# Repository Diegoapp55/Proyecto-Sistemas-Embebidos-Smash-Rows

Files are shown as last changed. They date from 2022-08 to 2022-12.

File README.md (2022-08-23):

# Proyecto-Sistemas-Embebidos
Repositorio para el proyecto de Sistemas Embebidos 2022-2: Smash Rows

En la wiki de este repositorio se encuentra la documentación al respecto del proyecto.

Integrantes: 
* Raúl Andrés Guzmán Mayorga
* Sergio Andrés Guevara Contreras
* Diego Alejandro Sánchez Mendoza
* Eduardo Toro Bernal

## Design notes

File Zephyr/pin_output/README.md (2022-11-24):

# GPIO output

Compilar firmware

```bash
make b
```

Subir firmware a esp32

```bash
make f
```

Conectarse por puerto serial al esp32

```bash
make t
```

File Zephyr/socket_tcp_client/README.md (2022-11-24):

# Cliente TCP

En este ejemplo el esp32 se conecta a la red wifi, solicita una ip a través del dhcp para finalmente conectarse
a un servicio 

## ¿Cómo reproducir este ejemplo?

1. Se requiere inicar el server, para lo cual deberá construir el servicio que se encuentra en `tcp_linux_server/`
para luego lanzarlo en la terminal, siga las instrucciones que encuentra en el README.md de ese directorio.

2. Deberá construir el firmware para el esp32, para lo cual modifique los siguientes datos en el prj.conf

## Comando útiles

* Consultar la ip asociada al esp32 desde el PC

```bash
sudo arp-scan --localnet
```

* Consultar la ip desde la uart-shell de zephyr os en el esp32

```bash
net iface
```

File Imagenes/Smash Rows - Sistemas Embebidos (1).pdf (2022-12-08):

# 2. ACTORES

# 1. CONTEXTO

## 3. PROPUESTA: SMASH ROWS

# SMASH ROWS

## Plataforma para agilizar las filas en las EPS

## 5. CONTROL ELECTRÓNICO

# 4. COMPONENTES

## 6. PROGRAMACIÓN

## 7. APLICACIONES

Sergio Andrés Guevara Contreras Raúl Andrés Guzmán Mayorga Diego Alejandro Sanchez Mendoza Eduardo Toro Bernal

Las EPS velan por brindar procesos ágiles y sencillos a los pacientes.

Se presenta una poca eficiencia en la entrega de medicamentos.

Principales causas de las demoras: Alta demanda, mayor cantidad de usuarios y falta de puntos de distribución y personal encargado.

Esto genera largas filas de espera, causando incomodidad en los usuarios.

Pacientes.
Distribuidoras de
medicamentos de las EPS.
Ministerio de salud.

Entidades de las EPS encargadas de distribuir medicamentos.
Droguerías.
Supermercados.

Smash Rows en un dispositivo que le permite al usuario conocer la disponibilidad de medicamentos en un punto de atención. Así, si este lo desea, puede realizar una dispensación automática a caja de sus medicinas asignadas, agilizando el proceso de búsqueda y entrega de estas.

El control se realiza desde la ESP32, la cual se encarga de manejar las señales de los motores y el WiFi. Adicionalmente, cuenta con un Arduino UNO que mediante un pin GPIO le manda información de lectura del módulo RFID a la ESP32.

La programación utilizada se realizó en Zephyr, un sistema operativo que permite escalabilidad y adaptabilidad a múltiples dispositivos, además de ser OpenSource. Se realizó el código de control de los motores, así como la integración de una bandera para el RFID y la conexión a un servicio mediante WiFi.

## 8. DOCUMENTACIÓN

ESP32 WRoom.
Reguladores: AMS117-5V y AMS117-3.3V. Módulo RFID: RC522.
Motores (2) paso a paso: 28-BYJ-48. (https://pdf1.alldatasheet.com/datasheet-pdf/view/1245086/ETC1/28BYJ48.html) Driver - ULN2003.
Diodo: 1N4007.
Módulo Optoacoplador.

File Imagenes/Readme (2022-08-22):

Todas las imágenes empleadas en la Wiki se almacenarán acá, estas son meramente ilustrativas.

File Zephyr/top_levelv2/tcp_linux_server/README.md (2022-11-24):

# Servidor TCP

Servicio que imprime en la terminal el mensaje que es recibido por un cliente, el servicio está activo
por el puerto 3000.

* Construir servidor:

```bash
gcc server.c -o server
```

* Lanzar servicio:

```bash
./server
```

* Detener servicio:

Para detener el servicio basta con oprimir el Ctrl junto a **c** `^c`

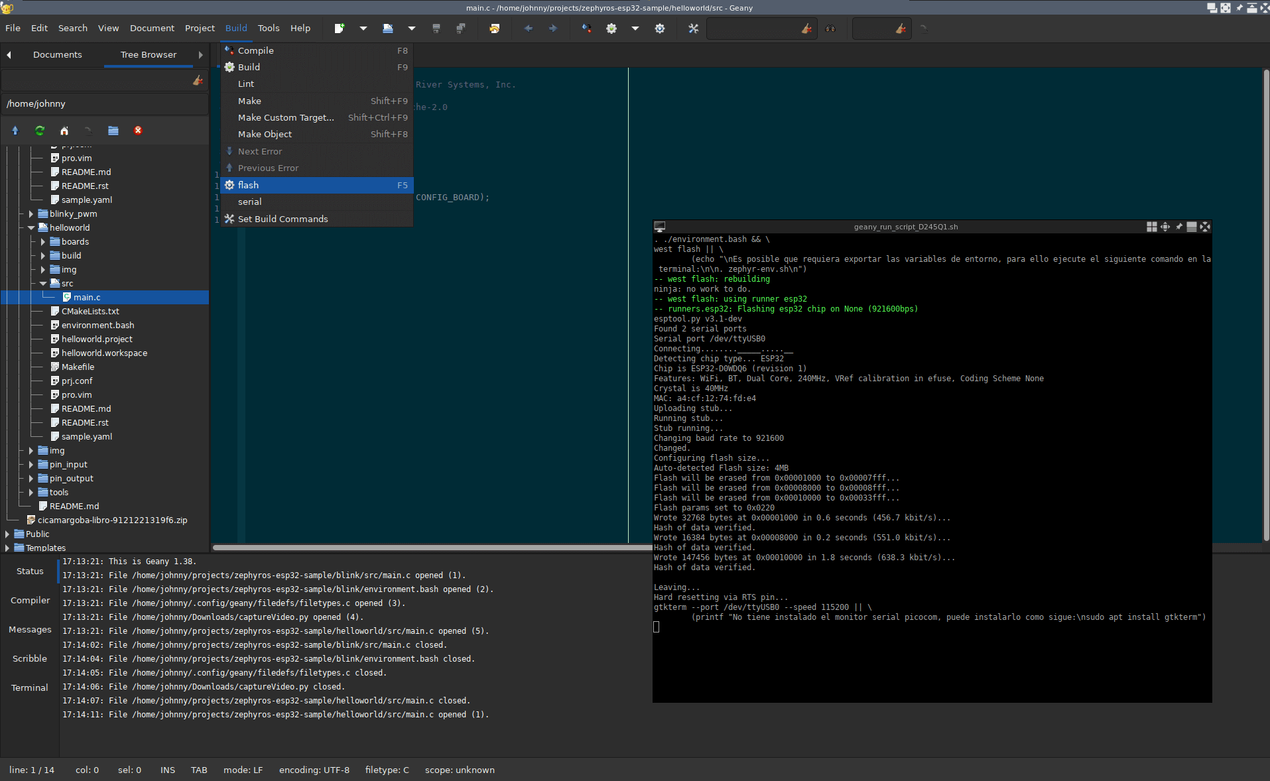
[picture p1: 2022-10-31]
Zephyr/img/geany-flash-esp32.png

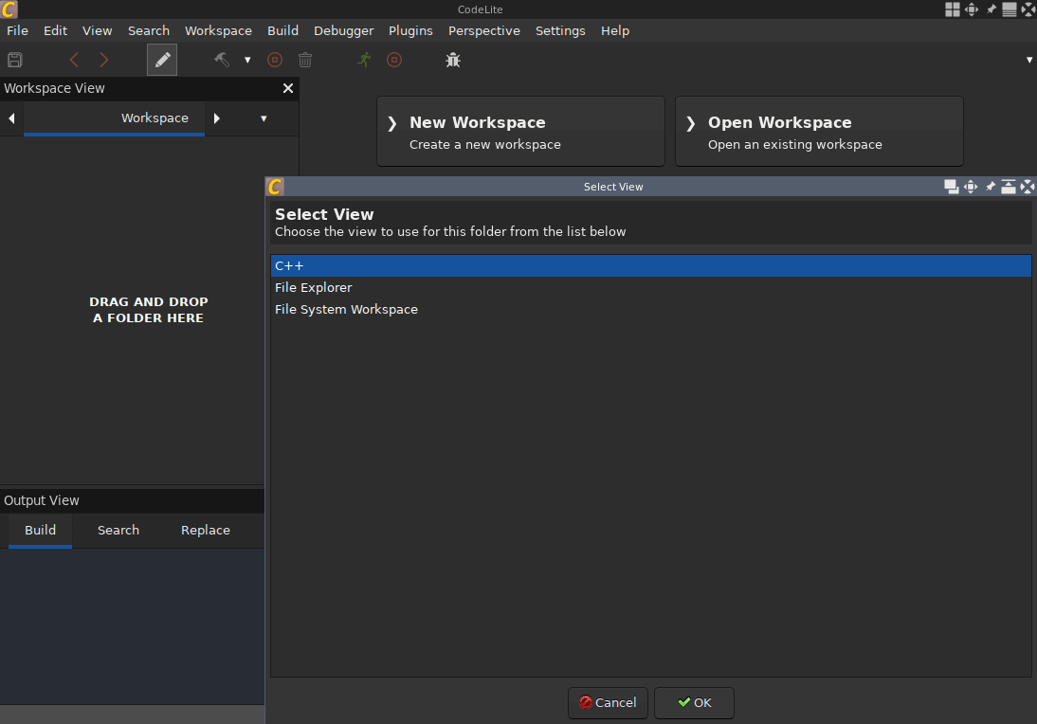
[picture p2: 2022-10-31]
Zephyr/img/codelite-select-view.png

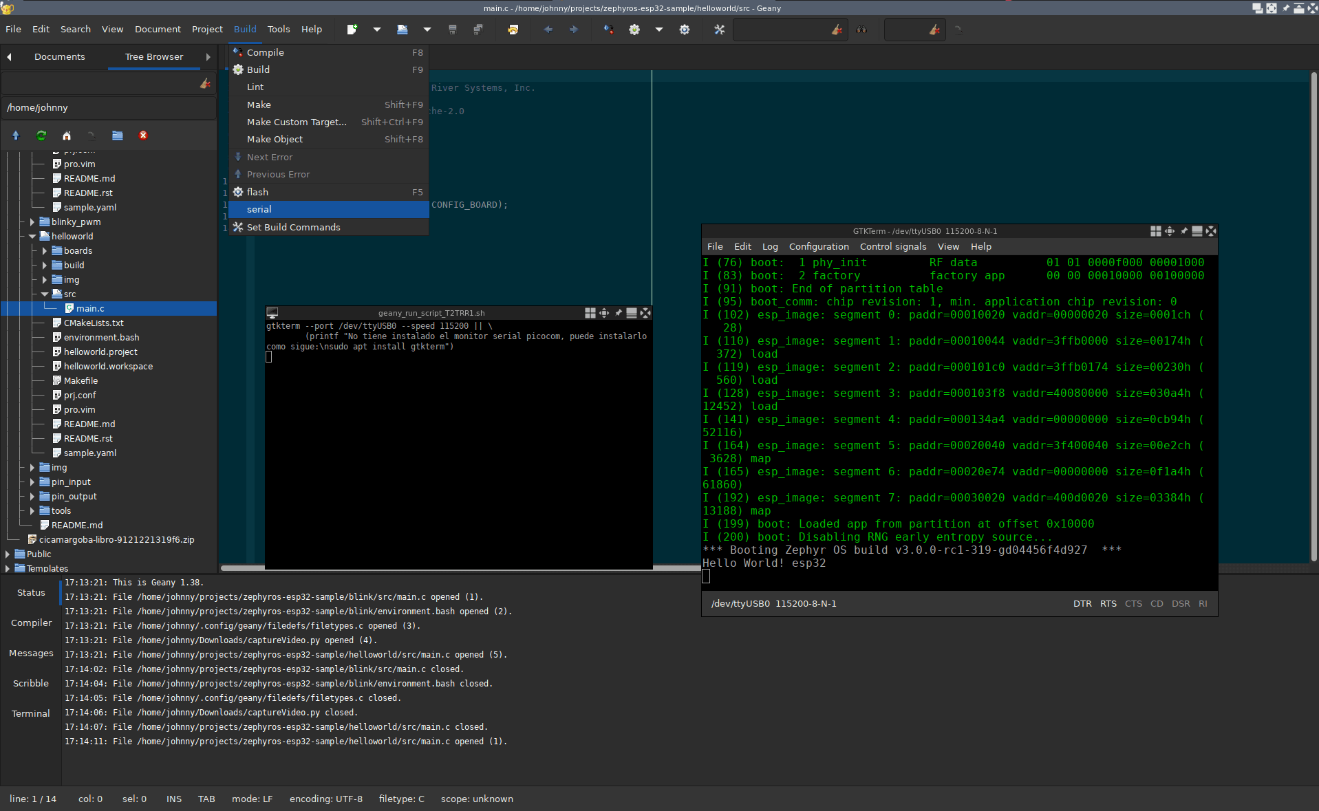
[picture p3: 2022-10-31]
Zephyr/img/geany-serial-esp32.png

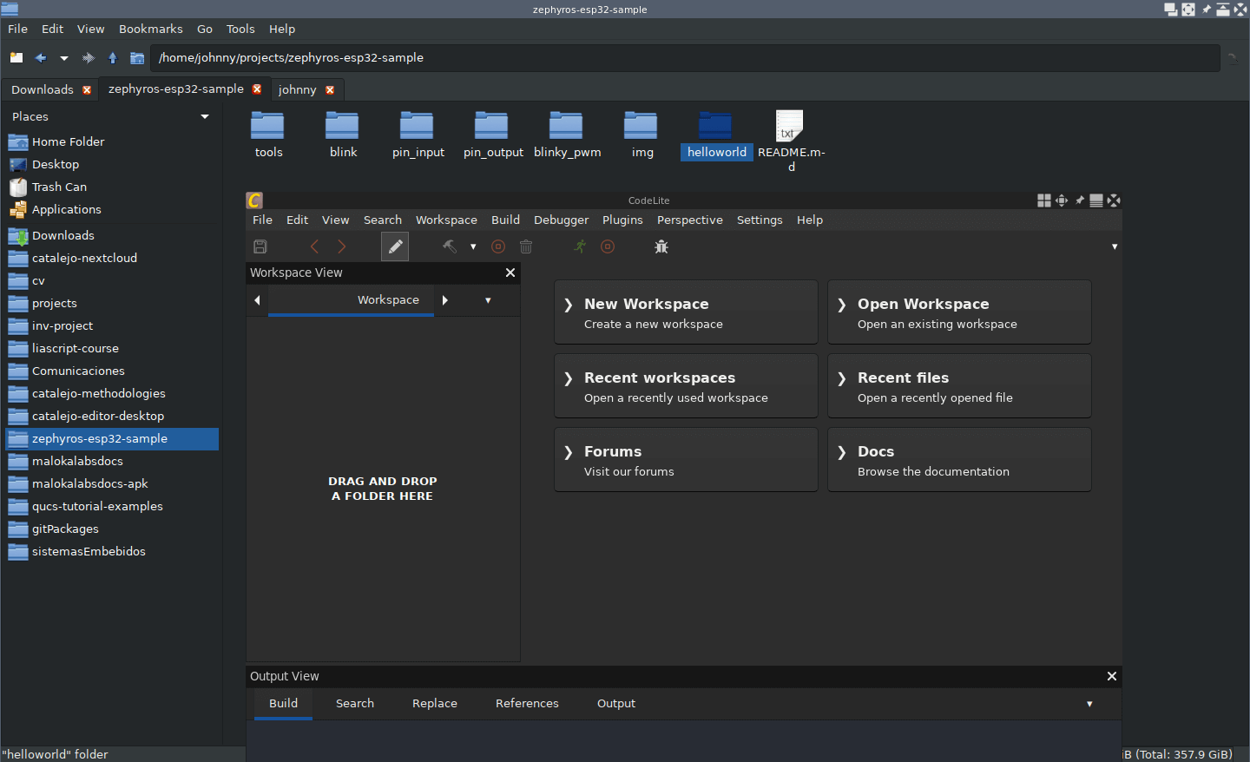
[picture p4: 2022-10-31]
Zephyr/img/codelite-drag-and-drop-prj.png

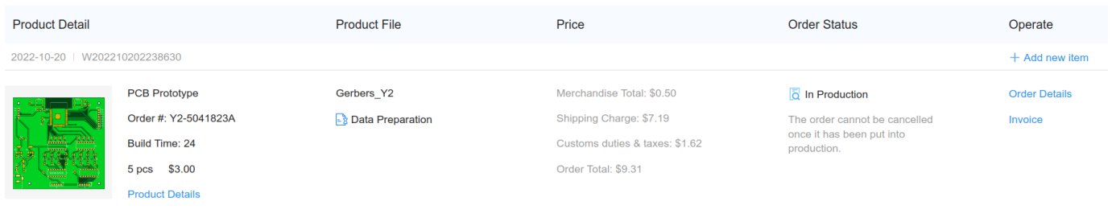
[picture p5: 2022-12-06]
Imagenes/orden_compra.png

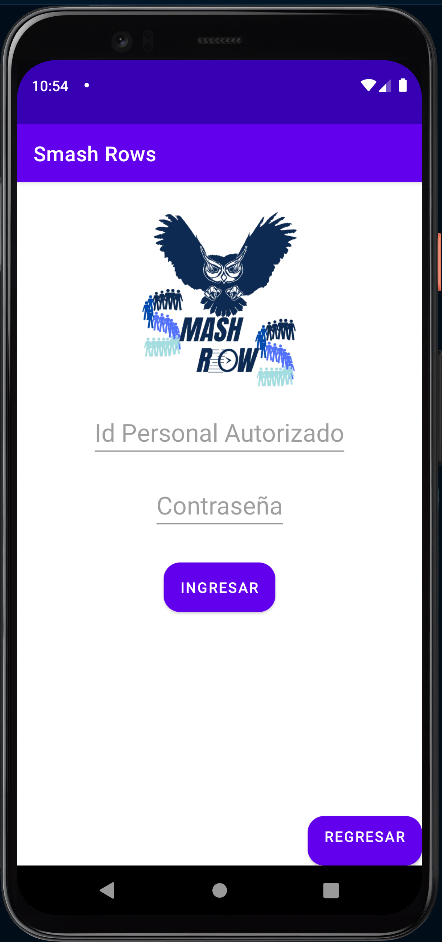
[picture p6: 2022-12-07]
Imagenes/App_Image/Login.png

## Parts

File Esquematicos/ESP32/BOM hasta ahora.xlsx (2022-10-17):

Column1 | Column2 | Column3
Source:
Date: | 16/10/2022 4:27:32 p. m.
Tool: | Eeschema (6.0.7)
Generator:
Component Count: | 72
Ref | Qnty | Value
BOOT1, | 1 | pulsador
C1, C2, C3, C4, C177, | 5 | 0.1uF
C11, C13, C15, C178, | 4 | 22uF
C12, C14, | 2 | 10uF
D1, | 1 | led
D2, | 1 | led
D3, | 1 | 1n4007
EN1, | 1 | pulsador
H1, H2, H3, H4, | 4 | NA
J1, | 1 | JST 1x5
J2, | 1 | JST 1x5
J3, | 1 | jack 12V
J4, | 1 | pin header hembra 1x5
Q1, Q2, Q3, Q4, Q5, Q6, Q7, Q8, | 8 | pnp s8550 o equiv
R1, R2, R3, R4, R9, R10, R11, R12, R13, R14, R15, R16, R21, R22, R23, R24, | 16 | 5.1kΩ
R5, R6, R7, R8, R17, R18, R19, R20, | 8 | 220Ω
R25, R27, | 2 | 10kΩ
R26, | 1 | 470Ω
R28, R29, | 2 | 56Ω
RRX1, | 1 | pend
RTX1, | 1 | pend
SW1, | 1 | dip switch x1
U1, U2, | 2 | ltv247 o equiv
U3, U4, | 2 | uln2003
U5, | 1 | ams1117-5V
U6, | 1 | ams1117-3V3
U7, | 1 | esp32wroom
U8, | 1 | rfid_rc522

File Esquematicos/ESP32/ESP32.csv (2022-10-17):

Source: | C:\Datos\UNAL\Materias\2022-2\Sistemas_Embebidos\Repositorio\Proyecto-Sistemas-Embebidos-Smash-Rows\Esquemáticos\ESP32\ESP32.kicad_sch
Date: | 16/10/2022 4:27:32 p. m.
Tool: | Eeschema (6.0.7)
Generator: | C:\Program Files\KiCad\6.0\bin\scripting\plugins/bom_csv_grouped_by_value_with_fp.py
Component Count: | 72
Ref | Qnty | Value | Cmp name | Footprint | Description | Vendor
BOOT1, | 1 | SW_Push | SW_Push | Button_Switch_SMD:SW_SPST_TL3305A | Push button switch, generic, two pins
C1, C2, C3, C4, C177, | 5 | 0.1uF | C | Capacitor_SMD:C_0603_1608Metric_Pad1.08x0.95mm_HandSolder | Unpolarized capacitor
C11, C13, C15, C178, | 4 | 22uF | C | Capacitor_SMD:C_0805_2012Metric_Pad1.18x1.45mm_HandSolder | Unpolarized capacitor
C12, C14, | 2 | 10uF | C_Polarized_US | Capacitor_SMD:C_0603_1608Metric_Pad1.08x0.95mm_HandSolder | Polarized capacitor, US symbol
D1, | 1 | Led_ON | IR26-21C_L110_TR8 | LED_SMD:LED_0603_1608Metric_Pad1.05x0.95mm_HandSolder | 940nm, 20 deg, Infrared LED, 1206
D2, | 1 | Led_holamundo | IR26-21C_L110_TR8 | LED_SMD:LED_0603_1608Metric_Pad1.05x0.95mm_HandSolder | 940nm, 20 deg, Infrared LED, 1206
D3, | 1 | 1N4007 | 1N4007 | Diode_SMD:D_SMA_Handsoldering | 1000V 1A General Purpose Rectifier Diode, DO-41
EN1, | 1 | SW_Push | SW_Push | Button_Switch_SMD:SW_SPST_TL3305A | Push button switch, generic, two pins
H1, H2, H3, H4, | 4 | MountingHole | MountingHole | MountingHole:MountingHole_2.5mm | Mounting Hole without connection
J1, | 1 | Conector para bobinas del motor 1 | Conn_01x05 | Connector_JST:JST_EH_B5B-EH-A_1x05_P2.50mm_Vertical | Generic connector, single row, 01x05, script generated (kicad-library-utils/schlib/autogen/connector/)
J2, | 1 | Conector para bobinas del motor 2 | Conn_01x05 | Connector_JST:JST_EH_B5B-EH-A_1x05_P2.50mm_Vertical | Generic connector, single row, 01x05, script generated (kicad-library-utils/schlib/autogen/connector/)
J3, | 1 | Barrel_Jack | Barrel_Jack | Connector_BarrelJack:BarrelJack_CLIFF_FC681465S_SMT_Horizontal | DC Barrel Jack
J4, | 1 | USB Programador | Conn_01x05_Female | Connector_PinHeader_2.54mm:PinHeader_1x05_P2.54mm_Vertical | Generic connector, single row, 01x05, script generated (kicad-library-utils/schlib/autogen/connector/)
Q1, Q2, Q3, Q4, Q5, Q6, Q7, Q8, | 8 | S8550 | S8550 | Package_TO_SOT_SMD:TSOT-23 | 0.7A Ic, 20V Vce, Low Voltage High Current PNP Transistor, TO-92
R1, R2, R3, R4, R9, R10, R11, R12, R13, R14, R15, R16, R21, R22, R23, R24, | 16 | 5.1k | R | Resistor_SMD:R_1206_3216Metric_Pad1.30x1.75mm_HandSolder | Resistor
R5, R6, R7, R8, R17, R18, R19, R20, | 8 | 220 | R | Resistor_SMD:R_1206_3216Metric_Pad1.30x1.75mm_HandSolder | Resistor
R25, R27, | 2 | 10k | R | Resistor_SMD:R_1206_3216Metric_Pad1.30x1.75mm_HandSolder | Resistor
R26, | 1 | 470 | R | Resistor_SMD:R_1206_3216Metric_Pad1.30x1.75mm_HandSolder | Resistor
R28, R29, | 2 | 56 | R | Resistor_SMD:R_1206_3216Metric_Pad1.30x1.75mm_HandSolder | Resistor
RRX1, | 1 | R | R | Resistor_SMD:R_1206_3216Metric_Pad1.30x1.75mm_HandSolder | Resistor
RTX1, | 1 | R | R | Resistor_SMD:R_1206_3216Metric_Pad1.30x1.75mm_HandSolder | Resistor
SW1, | 1 | SW_DIP_x01 | SW_DIP_x01 | Button_Switch_SMD:SW_DIP_SPSTx01_Slide_6.7x4.1mm_W6.73mm_P2.54mm_LowProfile_JPin | 1x DIP Switch, Single Pole Single Throw (SPST) switch, small symbol
U1, U2, | 2 | LTV-247 | LTV-247 | Package_SO:SOP-16_4.4x10.4mm_P1.27mm | DC Quad Optocoupler, Vce 80V, CTR 100-600%, SOP-16
U3, U4, | 2 | ULN2003A | ULN2003A | Package_SO:SOIC-16_4.55x10.3mm_P1.27mm | High Voltage, High Current Darlington Transistor Arrays, SOIC16/SOIC16W/DIP16/TSSOP16
U5, | 1 | AMS1117-5.0 | AMS1117-5.0 | Package_TO_SOT_SMD:SOT-223-3_TabPin2 | 1A Low Dropout regulator, positive, 5.0V fixed output, SOT-223
U6, | 1 | AMS1117-3.3 | AMS1117-3.3 | Package_TO_SOT_SMD:SOT-223-3_TabPin2 | 1A Low Dropout regulator, positive, 3.3V fixed output, SOT-223
U7, | 1 | ESP32-WROOM-32 | ESP32-WROOM-32 | RF_Module:ESP32-WROOM-32 | RF Module, ESP32-D0WDQ6 SoC, Wi-Fi 802.11b/g/n, Bluetooth, BLE, 32-bit, 2.7-3.6V, onboard antenna, SMD
U8, | 1 | RFID_RC522 | RFID_RC522 | Connector_JST:JST_EH_B8B-EH-A_1x08_P2.50mm_Vertical

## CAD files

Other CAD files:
CajitaFelizOficialHD/CajaFFFF.dwg
CajotaSmashRows/Cajotaxd.dwg

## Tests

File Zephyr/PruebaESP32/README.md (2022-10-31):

# Ejemplo HelloWorld esp32

## Instalación de herramientas

0. Lo primero que debe realizar es la instalación de Zephyr OS y el SDK o ToolChain de Zephyr OS. Para ello siga las instrucciones en la página oficial: [Instalación de Zephyr OS](https://docs.zephyrproject.org/latest/develop/getting_started/index.html)

Si no a instalado los submodulos de zephyr para espressif y además el toolchain de espressif,
deberá instalarlos en la siguiente secuencia:
Instaladas las herramientas descritas en el punto **0.** ahora se requiere instalar las herramientas
asociadas al **esp32** de zephyr, para ello desde esta terminal ejecute las instrucciones siguientes:

1. Exportación de variables de entorno para zephyr en la variante de espressif

```bash
. zephyr-env.sh esp
```

2. Instalación de toolchain espressif

```bash
make west-esp-tolchain-install
```

3. Instalación y actualización de submodulos de espressif en zephyr

```bash
make west-esp-update
```

4. Instala un monitor serial para poder hacer debug o ver resultados del proceso, se recomienda dos de ellos:

```bash
# comando de instalación
sudo apt install minicom picocom
```

5. Dar permisos al grupo *dialout* a su usuario linux, ejemplo de comando:

```bash
sudo usermod -a -G dialout user_name
```

**Observaciones**:

* En el anterior comando *user_name* debe ser reemplazado por su nombre de usuario, sino lo conoce puede ejecutar el comando `whoami` el cual le devolverá su nombre de usuario.

* Para que el anterior comando funcione deberá reiniciar el PC; después del reinicio, podrá verificar ejecutando el comando `groups`, allí deberá observar el grupo dialout, ejemplo:

  ```bash
  ~/projects  $  groups 
  johnny dialout cdrom floppy audio dip video plugdev netdev bluetooth lpadmin scanner
  ```

## Construcción y Flasheo

Ejecute los siguiente comando para construir el programa que correrá en el esp32:

```bash
make b
```

Con el esp32 conectado al PC proceda a programar la memoria flash del esp32 para
subir el programa con el siguiente comando:

```bash
make f
```

**Observación**: puede ejecutar la anterior secuencia de comandos en una sola instrucción como sigue: `make b f`

### Ver resultado por terminal

```bash
make t
```

En la placa de desarrollo oprima el botón de reiniciar y observe el resultado
en el monitor serial.

Ejemplo de resultado:

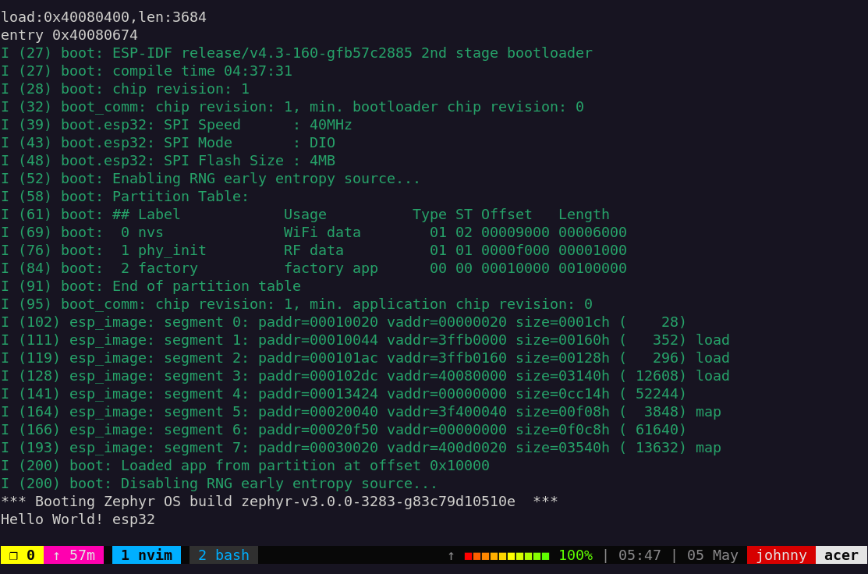
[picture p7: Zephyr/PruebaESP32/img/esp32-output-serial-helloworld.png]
test helloworld


**Observaciones**:

* Observe que en los comandos se hace uso de *make* para ver que otros comandos fueron planteados ejecute el comando `make help`. Para aprender más sobre *make* se invita a revisar su documentación.
* Puede ejecutar `make b f t` si quiere realizar el proceso de construcción, flasheo y monitoreo por serial en un solo comando.

## Referencias

https://www.zephyrproject.org/zephyr-rtos-on-esp32/

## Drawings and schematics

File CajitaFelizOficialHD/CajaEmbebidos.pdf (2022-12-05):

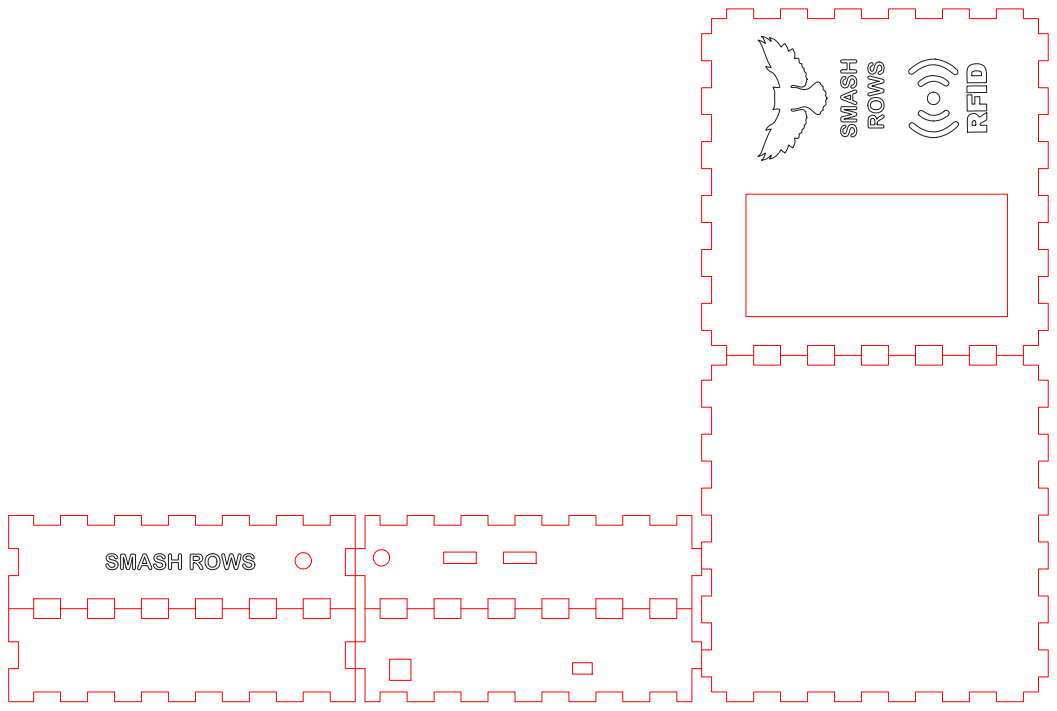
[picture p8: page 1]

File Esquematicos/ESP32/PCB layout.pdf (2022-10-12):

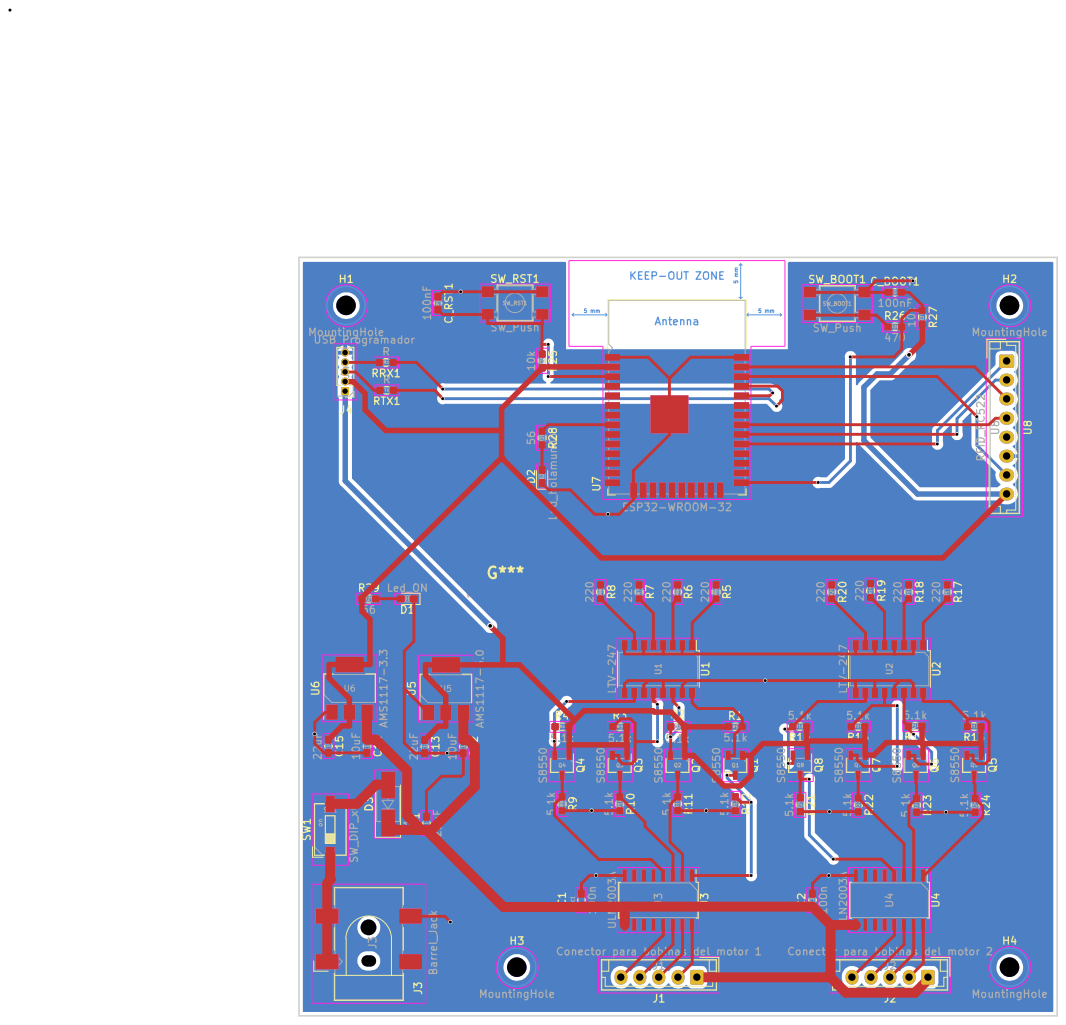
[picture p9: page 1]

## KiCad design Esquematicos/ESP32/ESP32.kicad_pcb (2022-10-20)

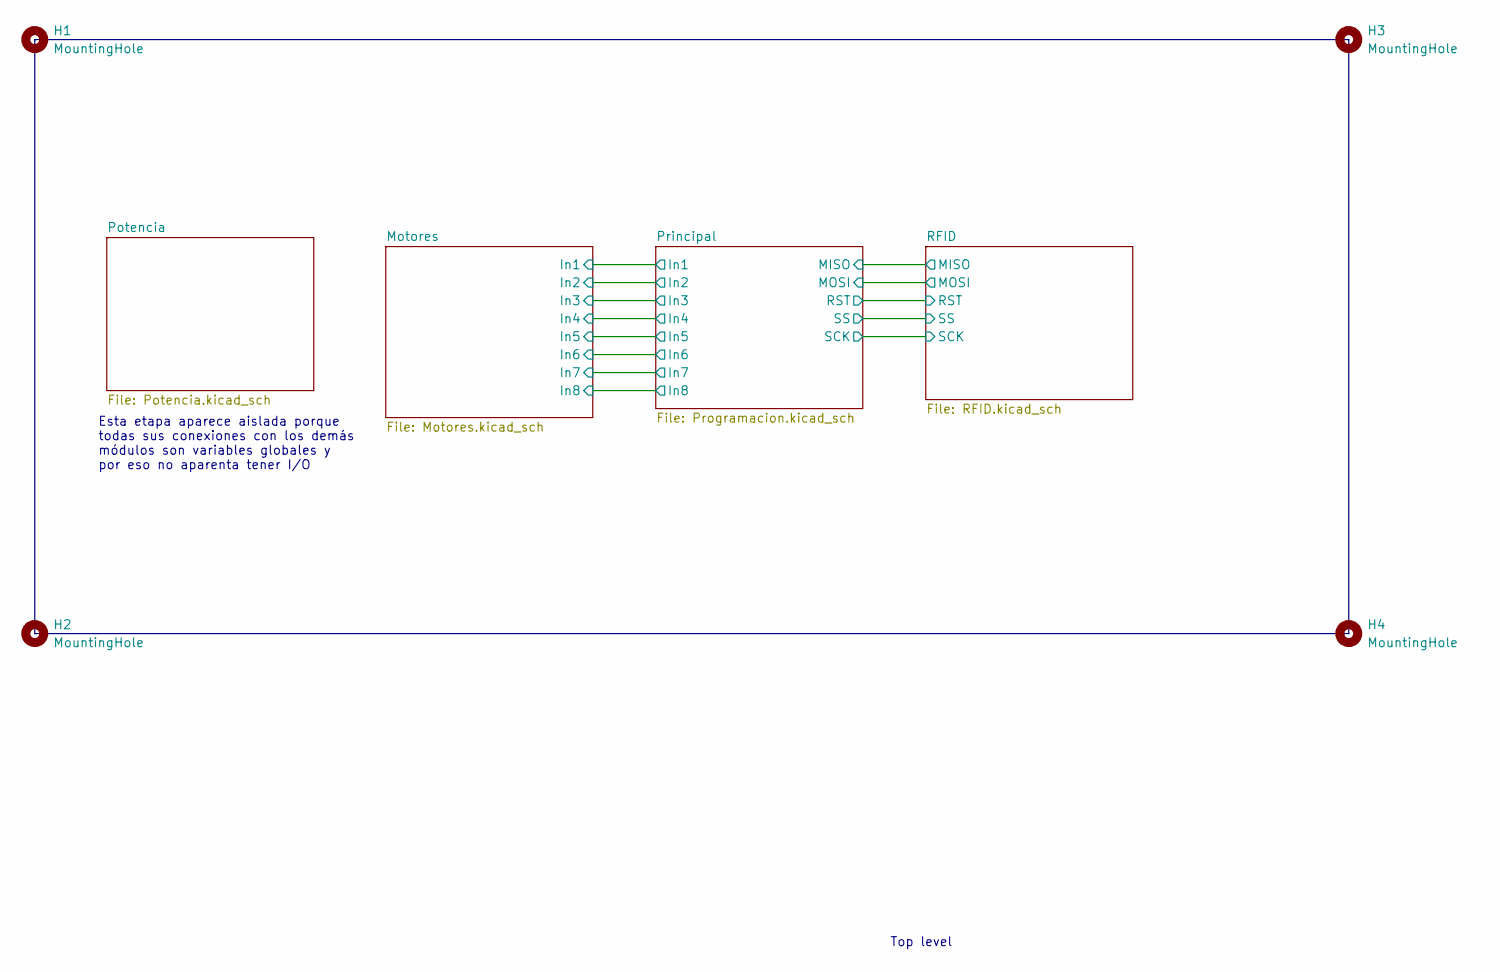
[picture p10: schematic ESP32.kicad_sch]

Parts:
H1, H2, H3, H4: MountingHole; MountingHole_2.5mm

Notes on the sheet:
Esta etapa aparece aislada porque todas sus conexiones con los demás módulos son variables globales y por eso no aparenta tener I/O
Top level

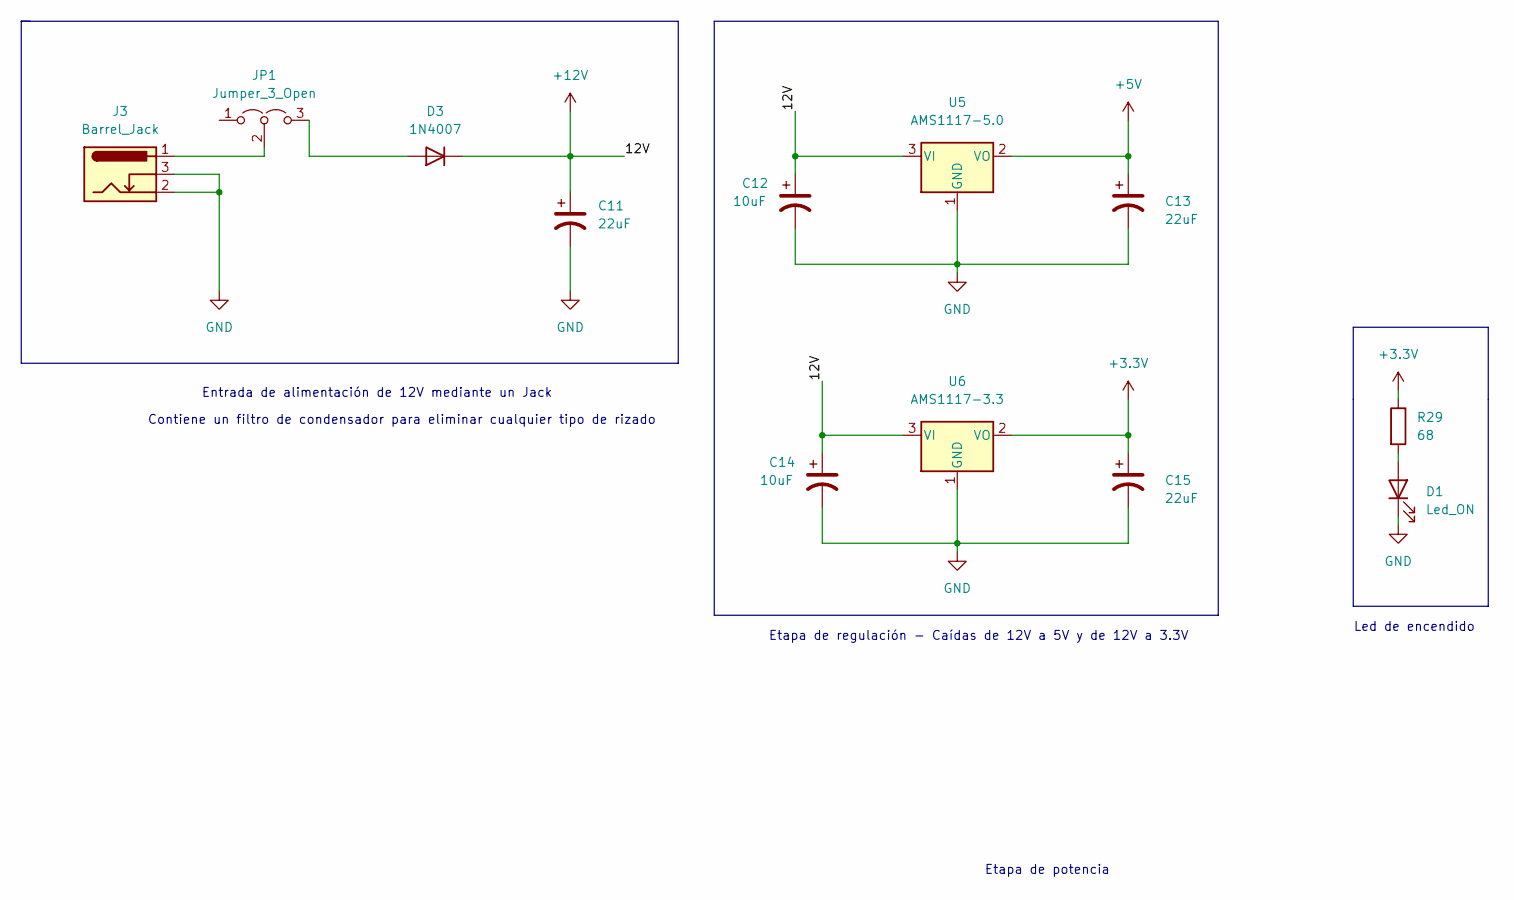
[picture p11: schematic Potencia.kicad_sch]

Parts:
C11, C13, C15: 22uF; C_0805_2012Metric_Pad1.18x1.45mm_HandSolder
C12, C14: 10uF; C_0805_2012Metric_Pad1.18x1.45mm_HandSolder
D1: Led_ON; LED_0603_1608Metric_Pad1.05x0.95mm_HandSolder
D3: 1N4007; D_SMA_Handsoldering
J3: Barrel_Jack; BarrelJack_GCT_DCJ200-10-A_Horizontal
JP1: Jumper_3_Open; PinHeader_1x03_P2.54mm_Vertical
R29: 68; R_1206_3216Metric_Pad1.30x1.75mm_HandSolder
U5: AMS1117-5.0; SOT-223-3_TabPin2
U6: AMS1117-3.3; SOT-223-3_TabPin2

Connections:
+3.3V: C15.1, R29.1, U6.2 (VO); also elsewhere on the board
+12V: C11.1, C12.1, C14.1, D3.1 (K), U5.3 (VI), U6.3 (VI)
GND: C11.2, C12.2, C13.2, C14.2, C15.2, D1.1 (K), J3.2, J3.3, U5.1 (GND), U6.1 (GND); also elsewhere on the board
unnamed: D1.2 (A), R29.2
unnamed: D3.2 (A), JP1.3 (B)
unnamed: J3.1, JP1.2 (C)

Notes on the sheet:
Entrada de alimentación de 12V mediante un Jack
Led de encendido
Contiene un filtro de condensador para eliminar cualquier tipo de rizado
Etapa de regulación - Caídas de 12V a 5V y de 12V a 3.3V
Etapa de potencia

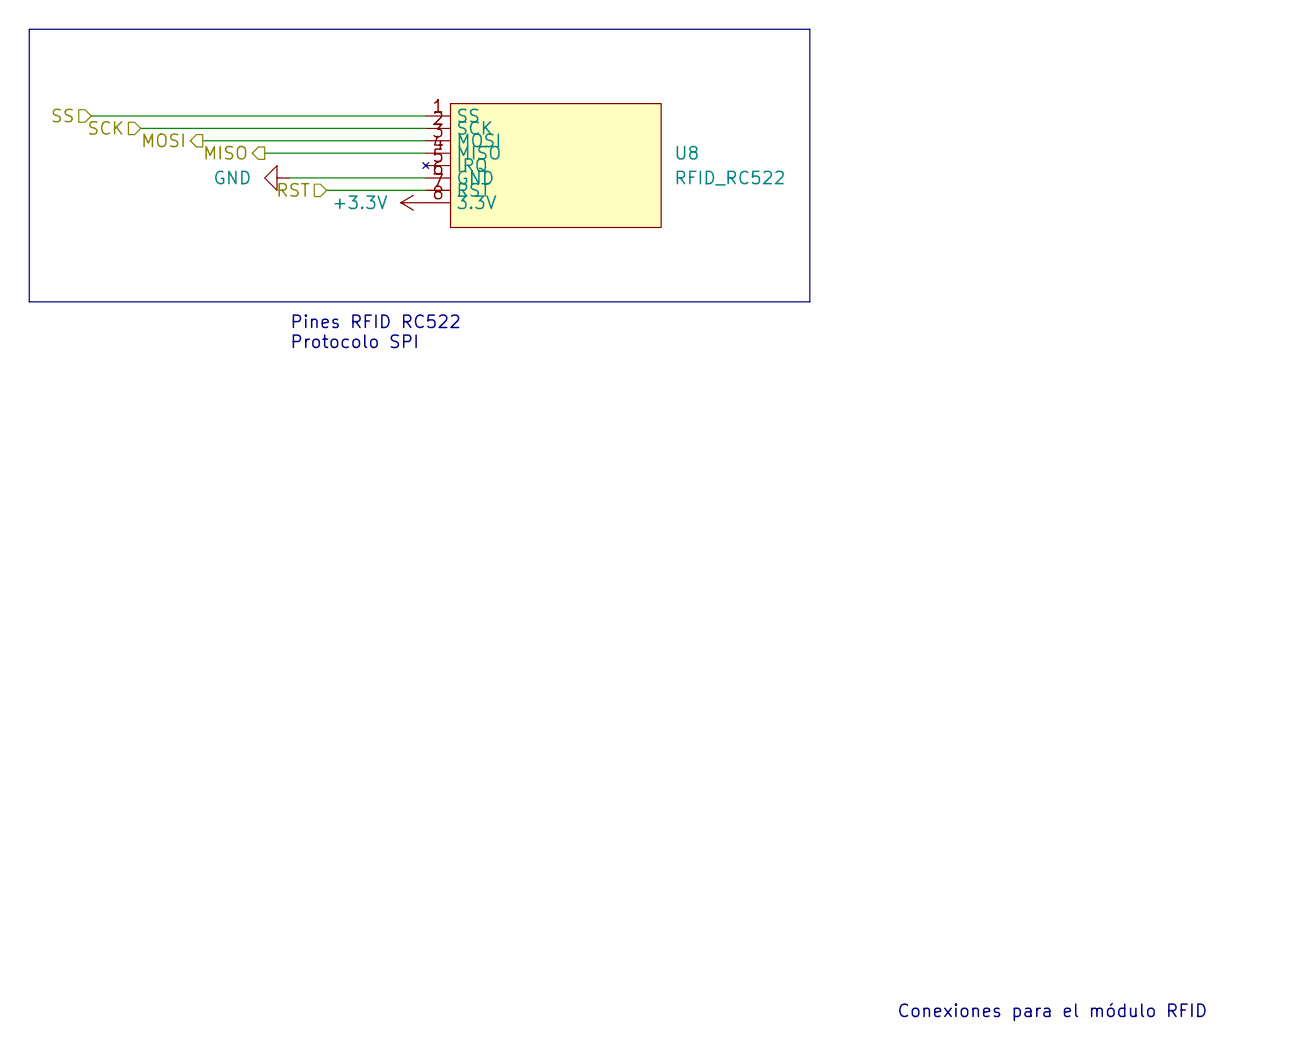
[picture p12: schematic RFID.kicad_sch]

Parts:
U8: RFID_RC522; JST_EH_B8B-EH-A_1x08_P2.50mm_Vertical

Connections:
+3.3V: U8.8 (3.3V); also elsewhere on the board
/Principal/MISO: U8.4 (MISO); also elsewhere on the board
/Principal/MOSI: U8.3 (MOSI); also elsewhere on the board
/Principal/RST: U8.7 (RST); also elsewhere on the board
/Principal/SCK: U8.2 (SCK); also elsewhere on the board
/Principal/SS: U8.1 (SS); also elsewhere on the board
GND: U8.6 (GND); also elsewhere on the board

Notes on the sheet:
Conexiones para el módulo RFID
Pines RFID RC522 Protocolo SPI

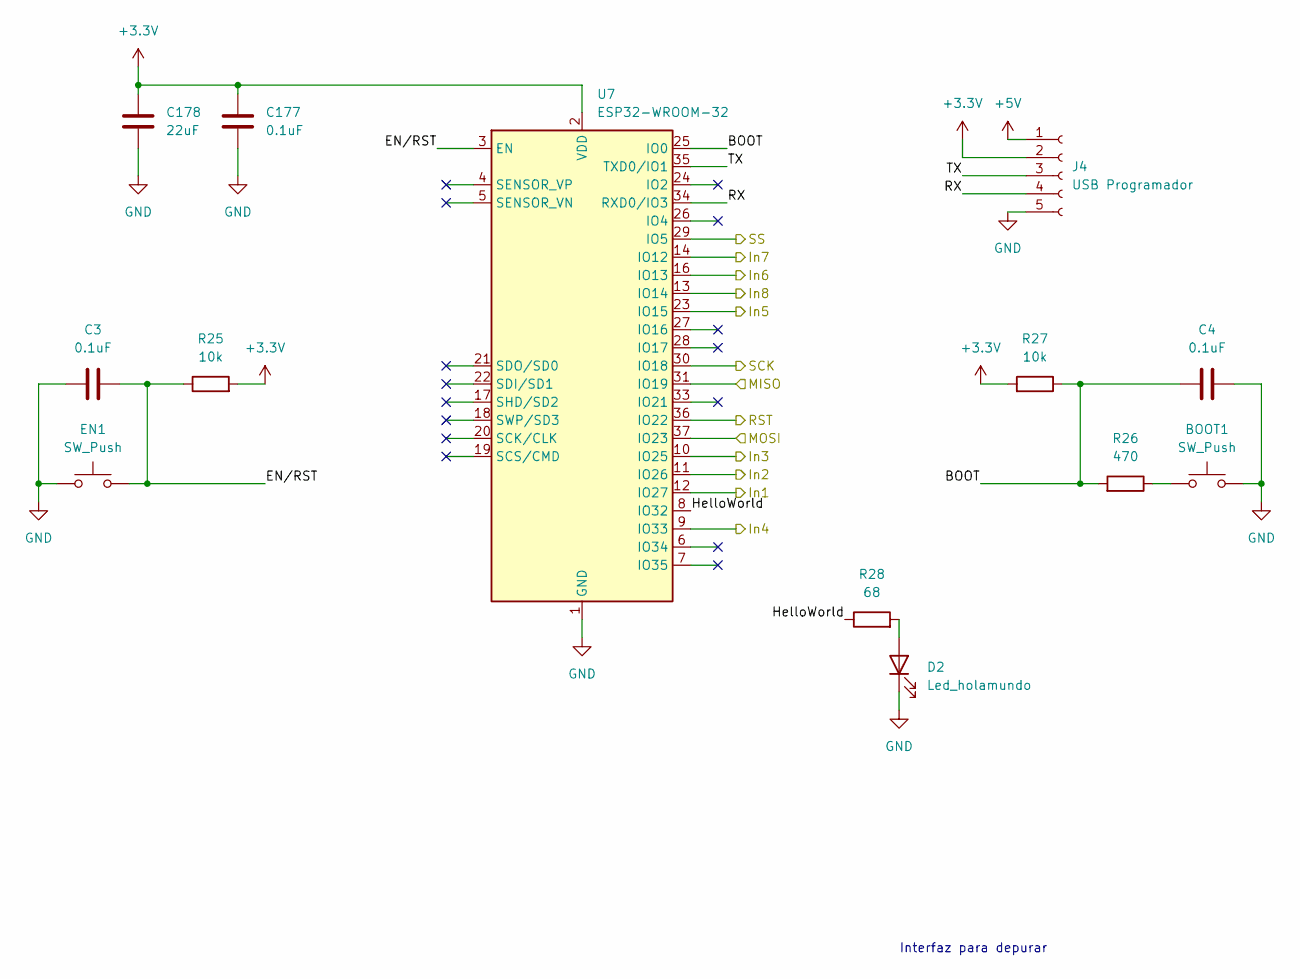
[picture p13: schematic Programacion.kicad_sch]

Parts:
BOOT1: SW_Push; SW_SPST_B3S-1000
C3, C4, C177: 0.1uF; C_0805_2012Metric_Pad1.18x1.45mm_HandSolder
C178: 22uF; C_0805_2012Metric_Pad1.18x1.45mm_HandSolder
D2: Led_holamundo; LED_0603_1608Metric_Pad1.05x0.95mm_HandSolder
EN1: SW_Push; SW_SPST_B3S-1000
J4: USB Programador; PinHeader_1x05_P2.54mm_Vertical
R25, R27: 10k; R_0805_2012Metric_Pad1.20x1.40mm_HandSolder
R26: 470; R_0805_2012Metric_Pad1.20x1.40mm_HandSolder
R28: 68; R_1206_3216Metric_Pad1.30x1.75mm_HandSolder
U7: ESP32-WROOM-32

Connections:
+3.3V: C177.1, C178.1, J4.2, R25.2, R27.2, U7.2 (VDD); also elsewhere on the board
/Motores/In1: U7.12 (IO27); also elsewhere on the board
/Motores/In2: U7.11 (IO26); also elsewhere on the board
/Motores/In3: U7.10 (IO25); also elsewhere on the board
/Motores/In4: U7.9 (IO33); also elsewhere on the board
/Motores/In5: U7.23 (IO15); also elsewhere on the board
/Motores/In6: U7.16 (IO13); also elsewhere on the board
/Motores/In7: U7.14 (IO12); also elsewhere on the board
/Motores/In8: U7.13 (IO14); also elsewhere on the board
/Principal/BOOT: C4.2, R26.2, R27.1, U7.25 (IO0)
/Principal/EN/RST: C3.2, EN1.2, R25.1, U7.3 (EN)
/Principal/HelloWorld: R28.1, U7.8 (IO32)
/Principal/MISO: U7.31 (IO19); also elsewhere on the board
/Principal/MOSI: U7.37 (IO23); also elsewhere on the board
/Principal/RST: U7.36 (IO22); also elsewhere on the board
/Principal/RX: J4.4, U7.34 (RXD0/IO3)
/Principal/SCK: U7.30 (IO18); also elsewhere on the board
/Principal/SS: U7.29 (IO5); also elsewhere on the board
/Principal/TX: J4.3, U7.35 (TXD0/IO1)
GND: BOOT1.1, C3.1, C4.1, C177.2, C178.2, D2.1 (K), EN1.1, J4.5, U7.1 (GND), U7.15 (GND), U7.38 (GND), U7.39 (GND); also elsewhere on the board
unnamed: BOOT1.2, R26.1
unnamed: D2.2 (A), R28.2

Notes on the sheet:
Interfaz para depurar

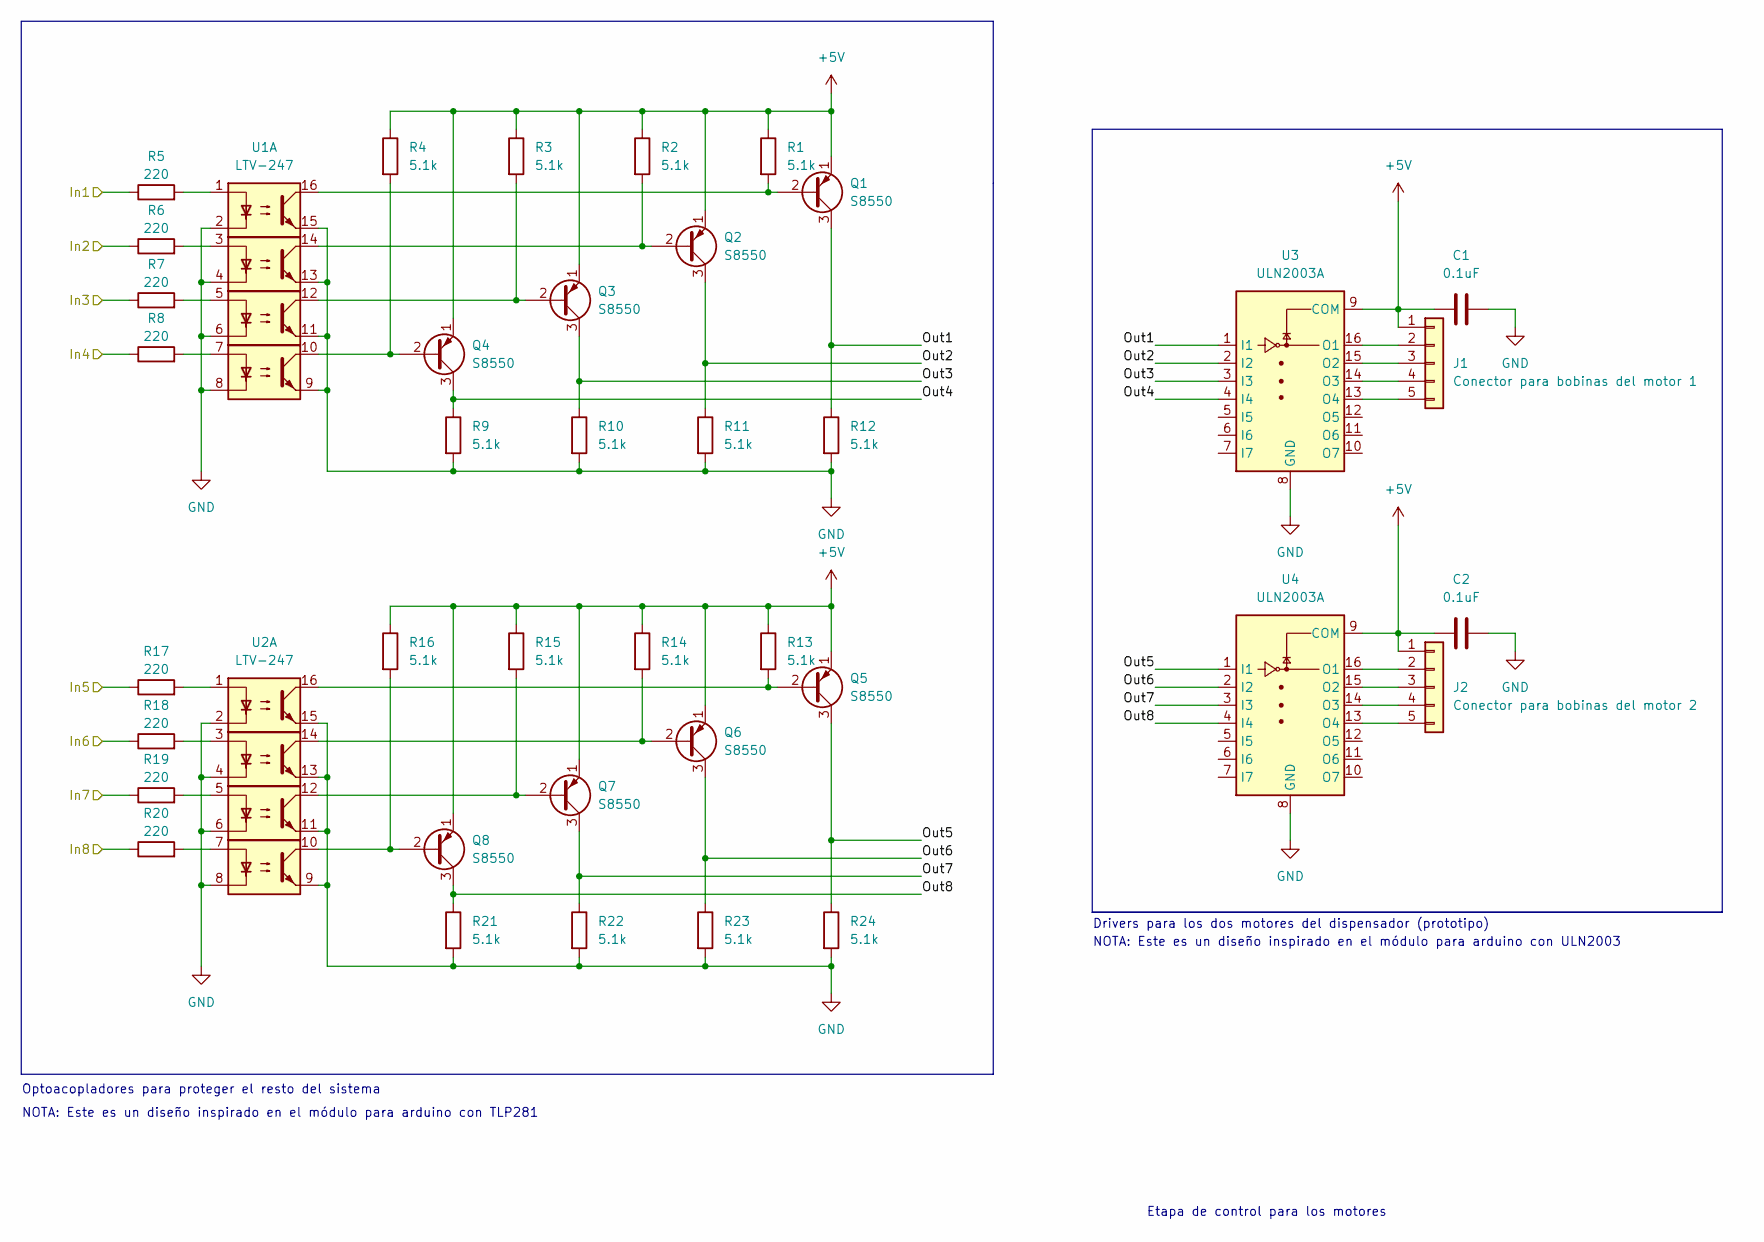
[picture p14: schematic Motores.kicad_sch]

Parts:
C1, C2: 0.1uF; C_0805_2012Metric_Pad1.18x1.45mm_HandSolder
J1: Conector para bobinas del motor 1; JST_EH_B5B-EH-A_1x05_P2.50mm_Vertical
J2: Conector para bobinas del motor 2; JST_EH_B5B-EH-A_1x05_P2.50mm_Vertical
Q1, Q2, Q3, Q4, Q5, Q6, Q7, Q8: S8550; TSOT-23
R1, R2, R3, R4, R9, R10, R11, R12, R13, R14, R15, R16, R21, R22, R23, R24: 5.1k; R_0805_2012Metric_Pad1.20x1.40mm_HandSolder
R5, R6, R7, R8, R17, R18, R19, R20: 220; R_0805_2012Metric_Pad1.20x1.40mm_HandSolder
U1, U2: LTV-247; DIP-16_W7.62mm_Socket
U3, U4: ULN2003A; DIP-16_W7.62mm_Socket

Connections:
/Motores/In1: R5.1; also elsewhere on the board
/Motores/In2: R6.1; also elsewhere on the board
/Motores/In3: R7.1; also elsewhere on the board
/Motores/In4: R8.1; also elsewhere on the board
/Motores/In5: R17.1; also elsewhere on the board
/Motores/In6: R18.1; also elsewhere on the board
/Motores/In7: R19.1; also elsewhere on the board
/Motores/In8: R20.1; also elsewhere on the board
/Motores/Out1: Q1.3 (C), R12.1, U3.1 (I1)
/Motores/Out2: Q2.3 (C), R11.1, U3.2 (I2)
/Motores/Out3: Q3.3 (C), R10.1, U3.3 (I3)
/Motores/Out4: Q4.3 (C), R9.1, U3.4 (I4)
/Motores/Out5: Q5.3 (C), R24.1, U4.1 (I1)
/Motores/Out6: Q6.3 (C), R23.1, U4.2 (I2)
/Motores/Out7: Q7.3 (C), R22.1, U4.3 (I3)
/Motores/Out8: Q8.3 (C), R21.1, U4.4 (I4)
GND: C1.2, C2.2, R9.2, R10.2, R11.2, R12.2, R21.2, R22.2, R23.2, R24.2, U1.2, U1.4, U1.6, U1.8, U1.9, U1.11, U1.13, U1.15, U2.2, U2.4, U2.6, U2.8, U2.9, U2.11, U2.13, U2.15, U3.8 (GND), U4.8 (GND); also elsewhere on the board
unnamed: J1.2, U3.16 (O1)
unnamed: J1.3, U3.15 (O2)
unnamed: J1.4, U3.14 (O3)
unnamed: J1.5, U3.13 (O4)
unnamed: J2.2, U4.16 (O1)
unnamed: J2.3, U4.15 (O2)
unnamed: J2.4, U4.14 (O3)
unnamed: J2.5, U4.13 (O4)
unnamed: Q1.2 (B), R1.2, U1.16
unnamed: Q2.2 (B), R2.2, U1.14
unnamed: Q3.2 (B), R3.2, U1.12
unnamed: Q4.2 (B), R4.2, U1.10
unnamed: Q5.2 (B), R13.2, U2.16
unnamed: Q6.2 (B), R14.2, U2.14
unnamed: Q7.2 (B), R15.2, U2.12
unnamed: Q8.2 (B), R16.2, U2.10
unnamed: R5.2, U1.1
unnamed: R6.2, U1.3
unnamed: R7.2, U1.5
unnamed: R8.2, U1.7
unnamed: R17.2, U2.1
unnamed: R18.2, U2.3
unnamed: R19.2, U2.5
unnamed: R20.2, U2.7

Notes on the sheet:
Optoacopladores para proteger el resto del sistema
Drivers para los dos motores del dispensador (prototipo)
NOTA: Este es un diseño inspirado en el módulo para arduino con ULN2003
NOTA: Este es un diseño inspirado en el módulo para arduino con TLP281
Etapa de control para los motores

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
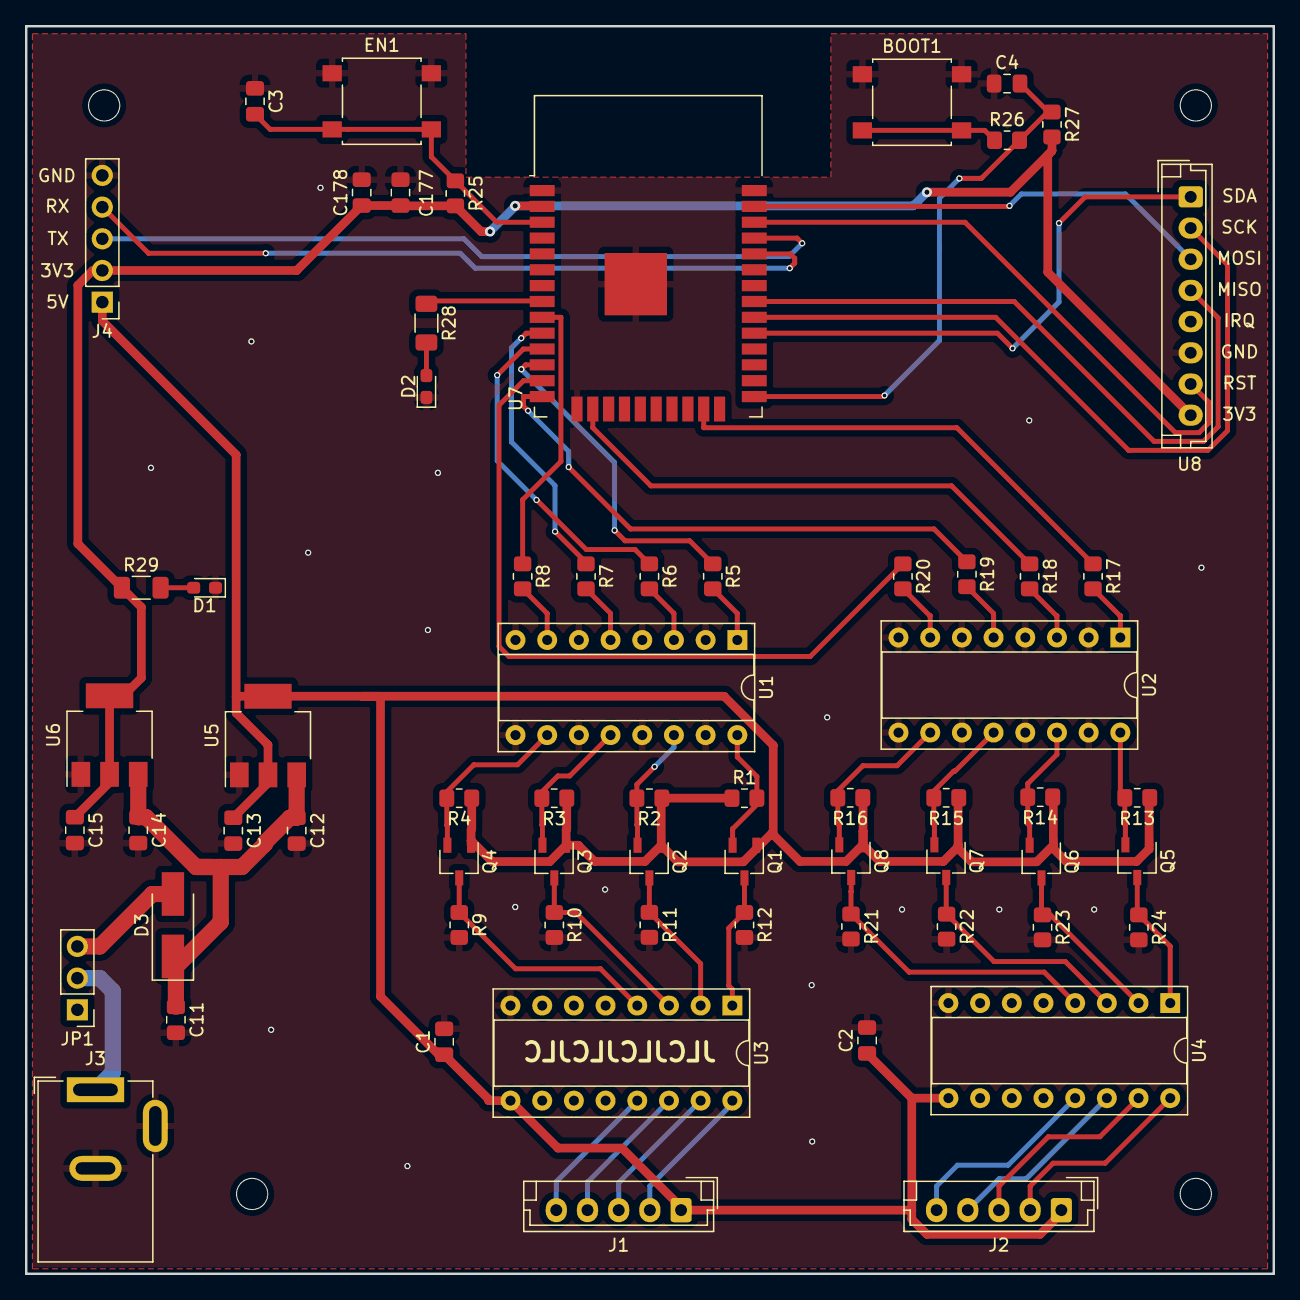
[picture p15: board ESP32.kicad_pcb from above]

Board: 2 copper layers, 100.0 x 100.0 mm, 70 parts (0 on the bottom side), 59 nets.

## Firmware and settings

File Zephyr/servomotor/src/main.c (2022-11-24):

/*
 * Copyright (c) 2020 Seagate Technology LLC
 *
 * SPDX-License-Identifier: Apache-2.0
 */

#include <zephyr/device.h>
#include <errno.h>
#include <zephyr/drivers/led.h>
#include <zephyr/sys/util.h>
#include <zephyr/kernel.h>
#include <zephyr/drivers/led.h>
/* #include "servo.h" // Driver */

#include <zephyr/logging/log.h>
LOG_MODULE_REGISTER(main, CONFIG_LOG_DEFAULT_LEVEL);

#if DT_NODE_HAS_STATUS(DT_INST(0, pwm_leds), okay)
#define LED_PWM_NODE_ID		DT_INST(0, pwm_leds)
#define LED_PWM_DEV_NAME	DEVICE_DT_NAME(LED_PWM_NODE_ID)
#else
#error "No LED PWM device found"
#endif

#define LED_PWM_LABEL(led_node_id) DT_PROP_OR(led_node_id, label, NULL),

const char *led_label[] = {
	DT_FOREACH_CHILD(LED_PWM_NODE_ID, LED_PWM_LABEL)
};

const int num_leds = ARRAY_SIZE(led_label);

#define MAX_BRIGHTNESS	35 // TODO 350
#define MIN_BRIGHTNESS 7 // TODO 70

#define FADE_DELAY_MS	200
#define FADE_DELAY	K_MSEC(FADE_DELAY_MS)

/**
 * @brief Run tests on a single LED using the LED API syscalls.
 *
 * @param led_pwm LED PWM device.
 * @param led Number of the LED to test.
 */
static void run_led_test(const struct device *led_pwm, uint8_t led)
{
	int err;
	uint16_t level;

	/* LOG_INF("Testing LED %d - %s", led, led_label[led] ? : "no label"); */

	/* Turn LED on. */
	err = led_on(led_pwm, led);
	if (err < 0) {
		LOG_ERR("err=%d", err);
		return;
	}
	LOG_INF("  Turned on");
	/* k_sleep(K_MSEC(1000)); */

	/* /1* Turn LED off. *1/ */
	/* err = led_off(led_pwm, led); */
	/* if (err < 0) { */
	/* 	LOG_ERR("err=%d", err); */
	/* 	return; */
	/* } */
	/* LOG_INF("  Turned off"); */
	/* k_sleep(K_MSEC(1000)); */

	/* Increase LED brightness gradually up to the maximum level. */
	LOG_INF("  Increasing brightness gradually");
	for (level = MIN_BRIGHTNESS; level <= MAX_BRIGHTNESS; level++) {
		/* led_set_brightness(led_pwm, led, 500); */
		err = led_set_brightness(led_pwm, led, level);
		if (err < 0)
    {
			LOG_ERR("err=%d brightness=%d\n", err, level);
		/* 	return; */
		} else
    {
			LOG_INF("porcentaje=%d\n", level);
    }
		k_sleep(FADE_DELAY);
	}
	/* k_sleep(K_MSEC(1000)); */

	/* Set LED blinking (on: 0.1 sec, off: 0.1 sec) */
	/* err = led_blink(led_pwm, led, 100, 100); */
	/* if (err < 0) { */
	/* 	LOG_ERR("err=%d", err); */
	/* 	return; */
	/* } */
	/* LOG_INF("  Blinking on: 0.1 sec, off: 0.1 sec"); */
	/* k_sleep(K_MSEC(5000)); */

	/* /1* Enable LED blinking (on: 1 sec, off: 1 sec) *1/ */
	/* err = led_blink(led_pwm, led, 1000, 1000); */
	/* if (err < 0) { */
	/* 	LOG_ERR("err=%d", err); */
	/* 	LOG_INF("  Cycle period not supported - on: 1 sec, off: 1 sec"); */
	/* } else { */
	/* 	LOG_INF("  Blinking on: 1 sec, off: 1 sec"); */
	/* } */
	/* k_sleep(K_MSEC(5000)); */

	/* /1* Turn LED off. *1/ */
	/* err = led_off(led_pwm, led); */
	/* if (err < 0) { */
	/* 	LOG_ERR("err=%d", err); */
	/* 	return; */
	/* } */
	/* LOG_INF("  Turned off, loop end"); */
}

void main(void)
{
	const struct device *led_pwm;
	uint8_t led;

  /* const struct device *servo1; */

	led_pwm = device_get_binding(LED_PWM_DEV_NAME);
	/* servo1 = device_get_binding(LED_PWM_DEV_NAME); */

	if (led_pwm) {
		LOG_INF("Found device %s", LED_PWM_DEV_NAME);
	} else {
		LOG_ERR("Device %s not found", LED_PWM_DEV_NAME);
		return;
	}
	/* if (servo1) { */
	/* 	LOG_INF("Found device %s", LED_PWM_DEV_NAME); */
	/* } else { */
	/* 	LOG_ERR("Device %s not found", LED_PWM_DEV_NAME); */
	/* 	return; */
	/* } */

	if (!num_leds) {
		LOG_ERR("No LEDs found for %s", LED_PWM_DEV_NAME);
		return;
	}
	/* if (!num_leds) { */
	/* 	LOG_ERR("No LEDs found for %s", LED_PWM_DEV_NAME); */
	/* 	return; */
	/* } */

	do {
		for (led = 0; led < num_leds; led++) {
			run_led_test(led_pwm, led);
		}
	} while (true);
}

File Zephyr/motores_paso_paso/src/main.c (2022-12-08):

/*
 * Copyright (c) 2016 Intel Corporation
 *
 * SPDX-License-Identifier: Apache-2.0
 */

#include <zephyr/kernel.h>
#include <zephyr/drivers/gpio.h>
#include <esp_log.h>

/* 1000 msec = 1 sec */
#define SLEEP_TIME   3

/* Define all coils for the motors */
/*Nodo del blink para depurar*/
#define LED0_NODE DT_ALIAS(led0)
/*Nodos del motor 1*/
#define COIL1_NODE DT_ALIAS(coil1alias)
#define COIL2_NODE DT_ALIAS(coil2alias)
#define COIL3_NODE DT_ALIAS(coil3alias)
#define COIL4_NODE DT_ALIAS(coil4alias)

/*Nodos del motor 2*/
#define COIL5_NODE DT_ALIAS(coil5alias)
#define COIL6_NODE DT_ALIAS(coil6alias)
#define COIL7_NODE DT_ALIAS(coil7alias)
#define COIL8_NODE DT_ALIAS(coil8alias)

/*Nodo del RFID*/
#define RFID_NODE DT_ALIAS(rfid0alias)

#define SUCCESSFUL 0
#define OK 0
#define ERROR 1

/*Llamado a los pines reales del led*/
static const struct gpio_dt_spec led = GPIO_DT_SPEC_GET(LED0_NODE, gpios);

/*Llamado a los pines reales motor 1*/
static const struct gpio_dt_spec coil1 = GPIO_DT_SPEC_GET(COIL1_NODE, gpios);
static const struct gpio_dt_spec coil2 = GPIO_DT_SPEC_GET(COIL2_NODE, gpios);
static const struct gpio_dt_spec coil3 = GPIO_DT_SPEC_GET(COIL3_NODE, gpios);
static const struct gpio_dt_spec coil4 = GPIO_DT_SPEC_GET(COIL4_NODE, gpios);

/*Llamado a los pines reales motor 2*/
static const struct gpio_dt_spec coil5 = GPIO_DT_SPEC_GET(COIL5_NODE, gpios);
static const struct gpio_dt_spec coil6 = GPIO_DT_SPEC_GET(COIL6_NODE, gpios);
static const struct gpio_dt_spec coil7 = GPIO_DT_SPEC_GET(COIL7_NODE, gpios);
static const struct gpio_dt_spec coil8 = GPIO_DT_SPEC_GET(COIL8_NODE, gpios);

/*Llamado al pin real del RFID*/
static const struct gpio_dt_spec rfid0 = GPIO_DT_SPEC_GET(RFID_NODE, gpios);

int leerTabla(int paso[], int posicion){
	int lectura = paso[posicion];
	return lectura;
}

int led_debug_init(void)
{
	if (!device_is_ready(led.port))
		return ERROR;
	if(gpio_pin_configure_dt(&led, GPIO_OUTPUT_ACTIVE) < 0)
    return ERROR;
  return SUCCESSFUL;
}

/* Función que configura los pines como salidas (o entradas) y con valor inicial igual a 0 */
void pins_config_init(void)
{
  int ret;
	ret = gpio_pin_configure_dt(&coil1, GPIO_OUTPUT_LOW);
  printk("%d ", ret);
	ret = gpio_pin_configure_dt(&coil2, GPIO_OUTPUT_LOW);
  printk("%d ", ret);
	ret = gpio_pin_configure_dt(&coil3, GPIO_OUTPUT_LOW);
  printk("%d ", ret);
	ret = gpio_pin_configure_dt(&coil4, GPIO_OUTPUT_LOW);
  printk("%d ", ret);
	ret = gpio_pin_configure_dt(&coil5, GPIO_OUTPUT_LOW);
  printk("%d ", ret);
	ret = gpio_pin_configure_dt(&coil6, GPIO_OUTPUT_LOW);
  printk("%d ", ret);
	ret = gpio_pin_configure_dt(&coil7, GPIO_OUTPUT_LOW);
  printk("%d ", ret);
	ret = gpio_pin_configure_dt(&coil8, GPIO_OUTPUT_LOW);
  printk("%d ", ret);

	/*pin del RFID*/
	ret = gpio_pin_configure_dt(&rfid0, GPIO_INPUT);
	printk("%d ", ret);																						/*Si hay un error puede ser acá, no estoy seguro de esto*/

}

void main(void)
{
	int ret = 0;
	int llego = 0;
	int arduino = 0;
	int vel_motor=1000;
	int count_step = 0;
	int round_step = 4076;


	const int numberSteps = 2600;
	const int tableSteps[4] = {0x8, 0x4, 0x2, 0x1};

	/*Lo del blink para depurar*/
	/* if (!device_is_ready(led.port)) { */
	/* 	return; */
	/* } */

	/* ret = gpio_pin_configure_dt(&led, GPIO_OUTPUT_ACTIVE); */
	/* if (ret < 0) { */
	/* 	return; */
	/* } */


  /* Iniciar led de debug */
  if(led_debug_init() == ERROR)
    return;

  /* Iniciar steppers */
  pins_config_init();

	//Si no se mueve lo suficiente, probar antes con while(1)
	while(1){
		arduino = gpio_pin_get_dt(&rfid0);
		printk("Lectura=%d, ",arduino);
		if (gpio_pin_get_dt(&rfid0)==1){
		llego = 1;


		while (count_step<numberSteps-100) { //En vez de 1 poner señal de control que se active con la orden de dispensar y se apague hasta que lo haga
			// ret = gpio_pin_set_dt(&coil1, 1/0)
			// Cambio el valor de los pines coilX
				for (int i = 0; i < 4; i++) {
					switch (tableSteps[i]) {
						case 0x8:
							gpio_pin_set_dt(&coil1, 0);
							gpio_pin_set_dt(&coil2, 1);
							gpio_pin_set_dt(&coil3, 1);
							gpio_pin_set_dt(&coil4, 1);
							break;
						case 0x4:
							gpio_pin_set_dt(&coil1, 1);
							gpio_pin_set_dt(&coil2, 0);
							gpio_pin_set_dt(&coil3, 1);
							gpio_pin_set_dt(&coil4, 1);
							break;
						case 0x2:
							gpio_pin_set_dt(&coil1, 1);
							gpio_pin_set_dt(&coil2, 1);
							gpio_pin_set_dt(&coil3, 0);
							gpio_pin_set_dt(&coil4, 1);
							break;
						case 0x1:
							gpio_pin_set_dt(&coil1, 1);
							gpio_pin_set_dt(&coil2, 1);
							gpio_pin_set_dt(&coil3, 1);
							gpio_pin_set_dt(&coil4, 0);
							break;
					}
					k_msleep(SLEEP_TIME);
					count_step++; //Revisar si esto está bien o es mejor ponerlo fuera del for para que cuente vueltasy no cada paso
				}


			// ret = gpio_pin_toggle_dt(&led);
			// if (ret < 0) {
			// 	return;
			// }
		}

	k_msleep(5*SLEEP_TIME);
	count_step=0;

		while (count_step<2*numberSteps) { //En vez de 1 poner señal de control que se active con la orden de dispensar y se apague hasta que lo haga
			// ret = gpio_pin_set_dt(&coil1, 1/0)
			// Cambio el valor de los pines coilX
				for (int i = 0; i < 4; i++) {
					switch (tableSteps[i]) {
						case 0x8:
							gpio_pin_set_dt(&coil5, 0);
							gpio_pin_set_dt(&coil6, 1);
							gpio_pin_set_dt(&coil7, 1);
							gpio_pin_set_dt(&coil8, 1);
							break;
						case 0x4:
							gpio_pin_set_dt(&coil5, 1);
							gpio_pin_set_dt(&coil6, 0);
							gpio_pin_set_dt(&coil7, 1);
							gpio_pin_set_dt(&coil8, 1);
							break;
						case 0x2:
							gpio_pin_set_dt(&coil5, 1);
							gpio_pin_set_dt(&coil6, 1);
							gpio_pin_set_dt(&coil7, 0);
							gpio_pin_set_dt(&coil8, 1);
							break;
						case 0x1:
							gpio_pin_set_dt(&coil5, 1);
							gpio_pin_set_dt(&coil6, 1);
							gpio_pin_set_dt(&coil7, 1);
							gpio_pin_set_dt(&coil8, 0);
							break;
					}
					k_msleep(SLEEP_TIME);
					count_step++; //Revisar si esto está bien o es mejor ponerlo fuera del for para que cuente vueltasy no cada paso
				}


			//ret = gpio_pin_toggle_dt(&led);
			//if (ret < 0) {
			//	return;
			//}
		}

		k_msleep(5*SLEEP_TIME);
		count_step=0;

	}
	else{
		llego = 0;
		// return;							/* Esto también ni idea, lo puse porque quedaba lendo*/
	}
	printk("Llego=%d\n", llego);
}
}

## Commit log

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2022-09-13 Esquemáticos para control de motores añadidos
    [Smash-Rows.kicad_pcb, Smash-Rows.kicad_sch]
2022-09-13 Agregada la parte de motores a la jerarquía de esquemáticos
    :+1:
    [ESP32.kicad_sch, Motores.kicad_sch, Potencia.kicad_sch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]
2022-09-13 Comentario sobre el zener de potencia
    Comentario agregado sobre el diodo utilizado en la etapa de potencia
    [Motores.kicad_sch, Potencia.kicad_sch]
2022-09-14 Añadido Modo Programación
    [ESP32.kicad_sch, Programacion.kicad_sch, RFID.kicad_sch]
2022-09-15 Cambios hechos al esquemático, faltan detalles
    Revisar el discord para dejar todo al día con el feedback de hoy
    [ESP32.kicad_sch, Motores.kicad_sch, Potencia.kicad_sch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]
2022-09-21 Actualizada la etapa de motores
    [ESP32.kicad_sch, Motores.kicad_sch]
2022-09-21 Actualización Potencia
    21/09/2022
    [ESP32.kicad_sch, Motores.kicad_sch, Potencia.kicad_sch]
2022-09-21 actualización raul
    [ESP32.kicad_sch, RFID.kicad_sch]
2022-09-21 Intentando ponerle footprints a los motores
    [ESP32.kicad_sch, Potencia.kicad_sch, Programacion.kicad_sch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]
2022-09-21 No hay cambios lol
    Lolazo
    [Potencia.kicad_sch]
2022-09-22 Arreglando los bugs xd
    [ESP32.kicad_sch, Motores.kicad_sch, Potencia.kicad_sch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]
2022-09-22 Cajas Potencia
    lolololol
    [Potencia.kicad_sch]
2022-09-22 actualización raul_2
    [ESP32.kicad_sch, RFID.kicad_sch]
2022-09-23 actualizacion raul 3.0
    [ESP32.kicad_sch, Programacion.kicad_sch]
2022-09-24 gente creo q borre cosas sin querer :(
    [ESP32.kicad_sch, RFID.kicad_sch]
2022-09-29 Mas commits :sunglasses:
    Agragados números de los componentes
    [ESP32.kicad_sch, Motores.kicad_sch, Potencia.kicad_sch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]
2022-09-29 Push mid :V
    [ESP32.kicad_sch, Motores.kicad_sch, Programacion.kicad_sch]
2022-10-04 Algunas huellas añadidas
    [ESP32.kicad_sch, Motores.kicad_sch, Programacion.kicad_sch]
2022-10-04 Potencia Cap
    xd?
    [ESP32.kicad_sch, Potencia.kicad_sch]
2022-10-04 me falta el led de programacion
    [ESP32.kicad_sch, Potencia.kicad_sch, Programacion.kicad_sch]
2022-10-04 Asignación Huellas de Resistencias
    [ESP32.kicad_sch, Motores.kicad_sch, Potencia.kicad_sch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]
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2022-10-04 Eliminando el error de autosave
    [ESP32.kicad_sch, Motores.kicad_sch, Potencia.kicad_sch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]
2022-10-04 Etiquetas globales para alimentación añadidas
    [ESP32.kicad_sch, Motores.kicad_sch, Potencia.kicad_sch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]
2022-10-04 añadí leds
    [ESP32.kicad_sch, Potencia.kicad_sch, Programacion.kicad_sch]
2022-10-06 Potencia - Final
    [ESP32.kicad_sch, Potencia.kicad_sch]
2022-10-09 Actualizadas las huellas de R y C
    De acuerdo con la recomendación del profe, ahora todas son 0603.
    [ESP32.kicad_sch, Motores.kicad_sch, Potencia.kicad_sch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]
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2022-10-10 wey noooooooooo (no guardé xd)
    [ESP32.kicad_pcb]
2022-10-10 PCB versión 1 (Faltan zonas de GND)
    [ESP32.dsn, ESP32.kicad_pcb, ESP32.kicad_sch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]
2022-10-11 Ruteo y zonas de cobre. Modo_serio.jpg
    [ESP32.kicad_pcb, ESP32.kicad_sch, Potencia.kicad_sch]
2022-10-11 Muchos cambios a la PCB
    Moví varios elementos para poder añadir los agujeros de montaje y agregué esos agujeros de montaje.
    También moví el pulsador de BOOT para que quede estéticamente mejor a ambos lados del módulo ESP32 WROOM
    Importante:
    Nos faltan todas las conexiones de los optoacopladores con la ESP 32 xD (urgente revisar cuales pines sirven para eso).
    [ESP32.csv, ESP32.kicad_pcb, ESP32.kicad_sch]
2022-10-12 Añadí las conexiones con los optoacopladores
    Además arreglé la posición de algunas vías.
    [ESP32.kicad_pcb, ESP32.kicad_sch, Motores.kicad_sch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]
2022-10-13 PCB terminada (pendiente de aprobación)
    :sunglasses: :sunglasses: :sunglasses:
    [ESP32.kicad_pcb, ESP32.kicad_sch, Motores.kicad_sch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]
2022-10-13 Actualizada la PCB con impresiones de qué es cada pin de los conectores
    Pendiente: Agregar capacitor de bypass en la entrada de 3v3 del ESP32 y listo, a comerciar con los chinos
    [ESP32.kicad_pcb, ESP32.kicad_sch, Programacion.kicad_sch]
2022-10-14 Placa con Logo
    [ESP32.kicad_pcb]
2022-10-16 Auxilio? Bypass 3.3V ESP32
    [ESP32.kicad_sch, Programacion.kicad_sch]
2022-10-17 Huellas actualizadas según los vendedores locales
    Falta la del optoacoplador y actualizar la placa. Además, dependiendo de la resñpuesta del profe tocaría re-diseñar todo :c
    [BOM hasta ahora.xlsx, ESP32.csv, ESP32.kicad_pcb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]
2022-10-18 PCB terminada
    Revisar los gerber y los drill :3
    [ESP32-B_Cu.gbr, ESP32-B_Mask.gbr, ESP32-B_Paste.gbr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]
2022-10-20 PCB lista uwu
    [ESP32-B_Cu.gbr, ESP32-B_Mask.gbr, ESP32-B_Paste.gbr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]
2022-10-20 Numero de Orden añadido
    [ESP32-B_Cu.gbr, ESP32-B_Mask.gbr, ESP32-B_Paste.gbr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]
2022-10-30 Agregué un comentario en uno de los archivos
    Ppara probar si nos deja hacer commits pull push y eso normalito
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2022-11-18 Codigo motores actualizado, no sirve ni el blinky :(
    Para que el profe nos ayude a encontrar el error en el código por fa. Gracias
    [main.c]
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2022-11-19 fix stepper example
2022-11-19 Borrando carpetas redundantes
    antes de hacer merge con la ayuda del profe
2022-11-20 Actualicé gitignore
    Para que no muestre como que se hicieron cambios en el repo cada que abrimos kicad para solo revisar algo y git piensa que cambiamos archivos
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2022-11-20 Parece que así si sirve el gitignore
    [BOM hasta ahora.xlsx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]
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2022-11-20 Pruebas 19-11
    Modificación del blink para que prenda 2 leds (Ese si funcionó, pero descubrí que al asignar el pin 27 para que haga GPIO_TOOGLE)
    Modifiqué también el de motores para lograr que funcione el blink de depuración con la ayuda del profe. Ahora toca ver si al escribir info en los pines del motor 1 (que ya inicializan sin problema), estaen verdad llega al motor y logra moverlo
    [main.c]
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2022-11-24 Actualizados los ejemplos de zephyr
    [pwm-servo.yaml]
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2022-12-04 Cajotaxd dwg
    [Cajotaxd.dwg]
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2022-12-05 Caja Actualizada
    [CajaFFFF.dwg]
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
